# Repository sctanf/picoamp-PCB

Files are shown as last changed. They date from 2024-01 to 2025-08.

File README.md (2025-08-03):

# indexspeakerdacsmol

compact usb-i2s dac using rp2040 and max98360a for powering speakers, like index bmr drivers

* I forgot the silkscreen for usb pins, but they should be clear from below images.
* 0201 components suck to work with.
* intended to use with a usb-c cable, however the CC wire needs 5.1K pull-down to ground which I forgot about

firmware for the device is at https://github.com/sctanf/picoamp-2

pcb|3d|dev-pcb|dev-3d
--|--|--|--
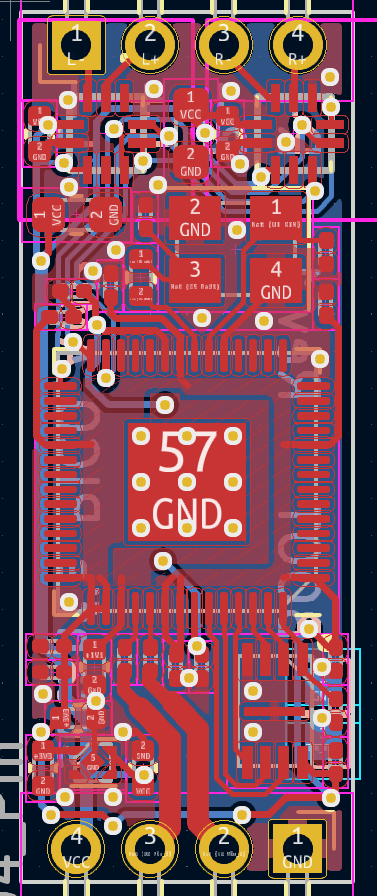
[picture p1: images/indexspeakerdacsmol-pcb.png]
pcb
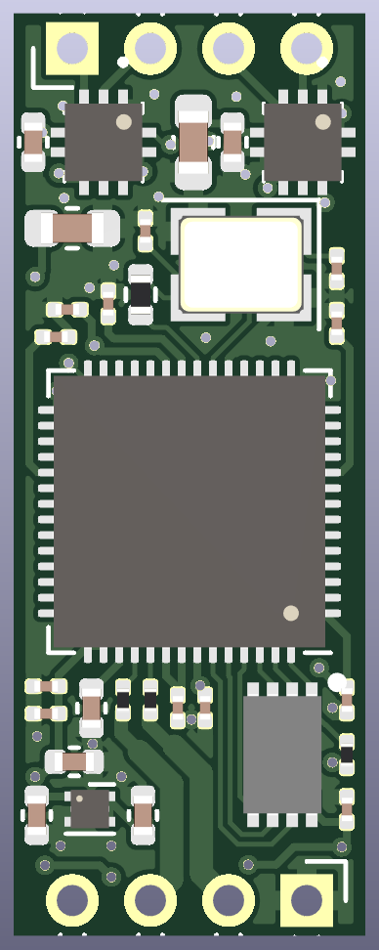
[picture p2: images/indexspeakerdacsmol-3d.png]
3d
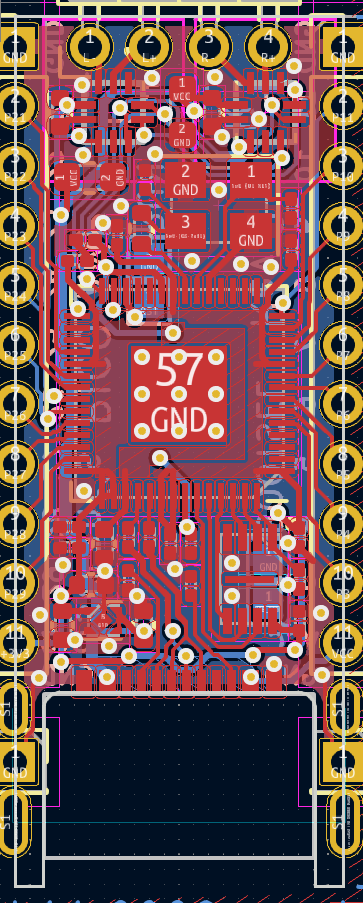
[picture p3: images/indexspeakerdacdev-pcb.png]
dev-pcb
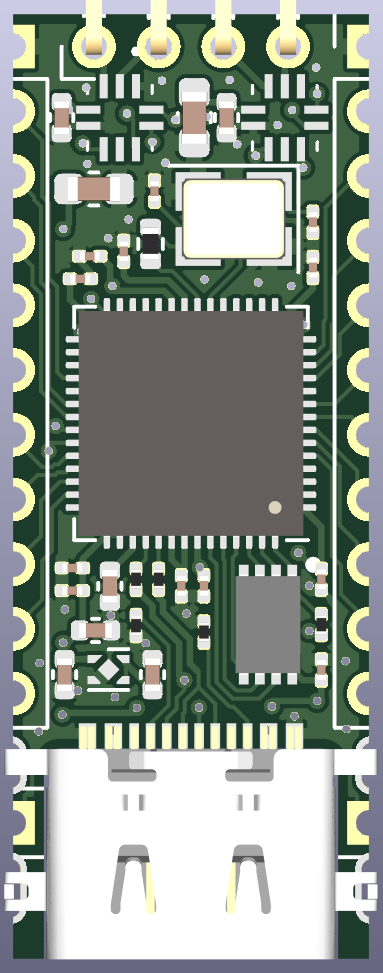
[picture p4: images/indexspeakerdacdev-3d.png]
dev-3d
|||

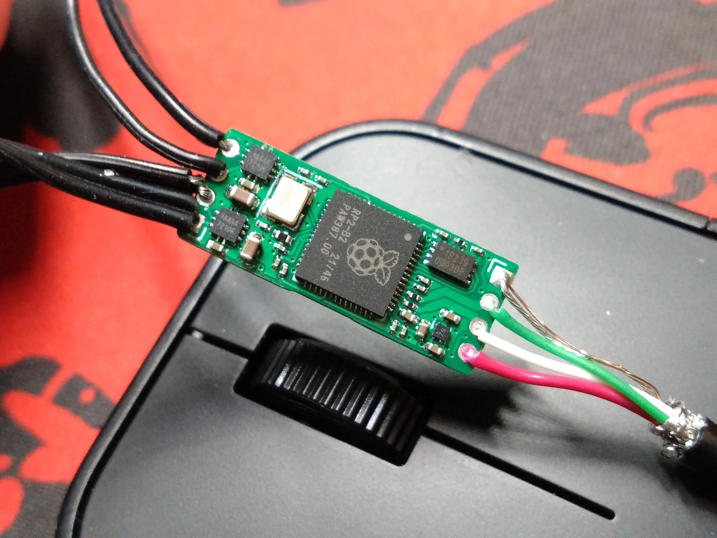
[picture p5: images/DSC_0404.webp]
finished board


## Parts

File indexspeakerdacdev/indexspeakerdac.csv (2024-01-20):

Reference | Value | Footprint | Datasheet | Manufacturer_Name | Manufacturer_Part_Number | Mouser Part Number | Qty
C1, C2 | 10uF | Capacitor_SMD:C_0603_1608Metric | ~ | Murata | GRM188C81A106MA73D | 81-GRM188C81A106MA3D | 2
C3, C4 | 0.1uF | Capacitor_SMD:C_0402_1005Metric | ~ | Murata | GRM155R61A104KA01J | 81-GRM15R61A104KA01J | 2
C5, C6 | 15pF | Capacitor_SMD:C_0201_0603Metric | ~ | Murata | GRM0335C1E150JA01D | 81-GRM0335C1E150JA1D | 2
C7, C8, C16, C18 | 1uF | Capacitor_SMD:C_0402_1005Metric | ~ | Murata | GRM155C81A105KA12J | 81-GRM155C81A105KA2J | 4
C12, C14, C15, C17, C19-C24 | 0.1uF | Capacitor_SMD:C_0201_0603Metric | ~ | Murata | GRM033C80J104KE15D | 81-GRM33C80J104KE15D | 10
IC1, IC2 | MAX98360AEFB+T | SamacSys_Parts:MAX98360AEFB | https://www.mouser.jp/datasheet/2/256/MAX98360A-MAX98360D-1839867.pdf | Analog Devices Inc. | MAX98360AEFB+T | 700-MAX98360AEFB+T | 2
IC3 | W25Q16JVUXIQ_TR | SamacSys_Parts:SON50P300X200X60-9N | https://componentsearchengine.com/Datasheets/1/W25Q16JVUXIQ TR.pdf | Winbond | W25Q16JVUXIQ TR | 454-W25Q16JVUXIQTR | 1
J1 | Conn_01x04_Pin | Connector_PinHeader_2.00mm:PinHeader_1x04_P2.00mm_Horizontal | ~ |  |  |  | 1
J2, J4 | Conn_01x11_Pin | Connector_PinHeader_2.00mm:PinHeader_1x11_P2.00mm_Vertical | ~ |  |  |  | 2
J3, J5 | Conn_01x01_Pin | Connector_PinHeader_2.00mm:PinHeader_1x01_P2.00mm_Vertical | ~ |  |  |  | 2
J6 | USB_C_Receptacle_USB2.0 |  | https://www.usb.org/sites/default/files/documents/usb_type-c.zip | Global Connector Technology (GCT) | USB4510-03-1-A | 640-USB4510031A | 1
R1 | 1k | Resistor_SMD:R_0402_1005Metric | ~ | Vishay | CRCW04021K00FKED | 71-CRCW0402-1.0K-E3 | 1
R2, R3 | 27R | Resistor_SMD:R_0201_0603Metric | ~ | YAGEO | RC0201FR-0727RL | 603-RC0201FR-0727RL | 2
R4 | 1k | Resistor_SMD:R_0201_0603Metric | ~ | Bourns | CR0201-FW-1001GLF | 652-CR0201FW-1001GLF | 1
R5, R6 | 5.1k | Resistor_SMD:R_0201_0603Metric | ~ | YAGEO | RC0201JR-075K1L | 603-RC0201JR-075K1L | 2
TP1-TP4 | TestPoint | TestPoint:TestPoint_Pad_1.0x1.0mm | ~ |  |  |  | 4
U1 | RP2040 | Package_DFN_QFN:QFN-56-1EP_7x7mm_P0.4mm_EP3.2x3.2mm | https://datasheets.raspberrypi.com/rp2040/rp2040-datasheet.pdf | Raspberry Pi | SC0914(7) | 358-SC09147 | 1
U2 | MIC5317-3.3xM5 | Package_DFN_QFN:UDFN-4-1EP_1x1mm_P0.65mm_EP0.48x0.48mm | https://ww1.microchip.com/downloads/aemDocuments/documents/OTH/ProductDocuments/DataSheets/MIC5317-High-Performance-Single-150mA-LDO-DS20006195B.pdf | Microchip | MIC5317-3.3YMT-TR | 494-MIC531733YMTTR | 1
Y1 | Crystal_GND24 | Crystal:Crystal_SMD_3225-4Pin_3.2x2.5mm | ~ | ECS | ECS-120-10-33-AGM-TR | 520-120-10-33-AGMT | 1

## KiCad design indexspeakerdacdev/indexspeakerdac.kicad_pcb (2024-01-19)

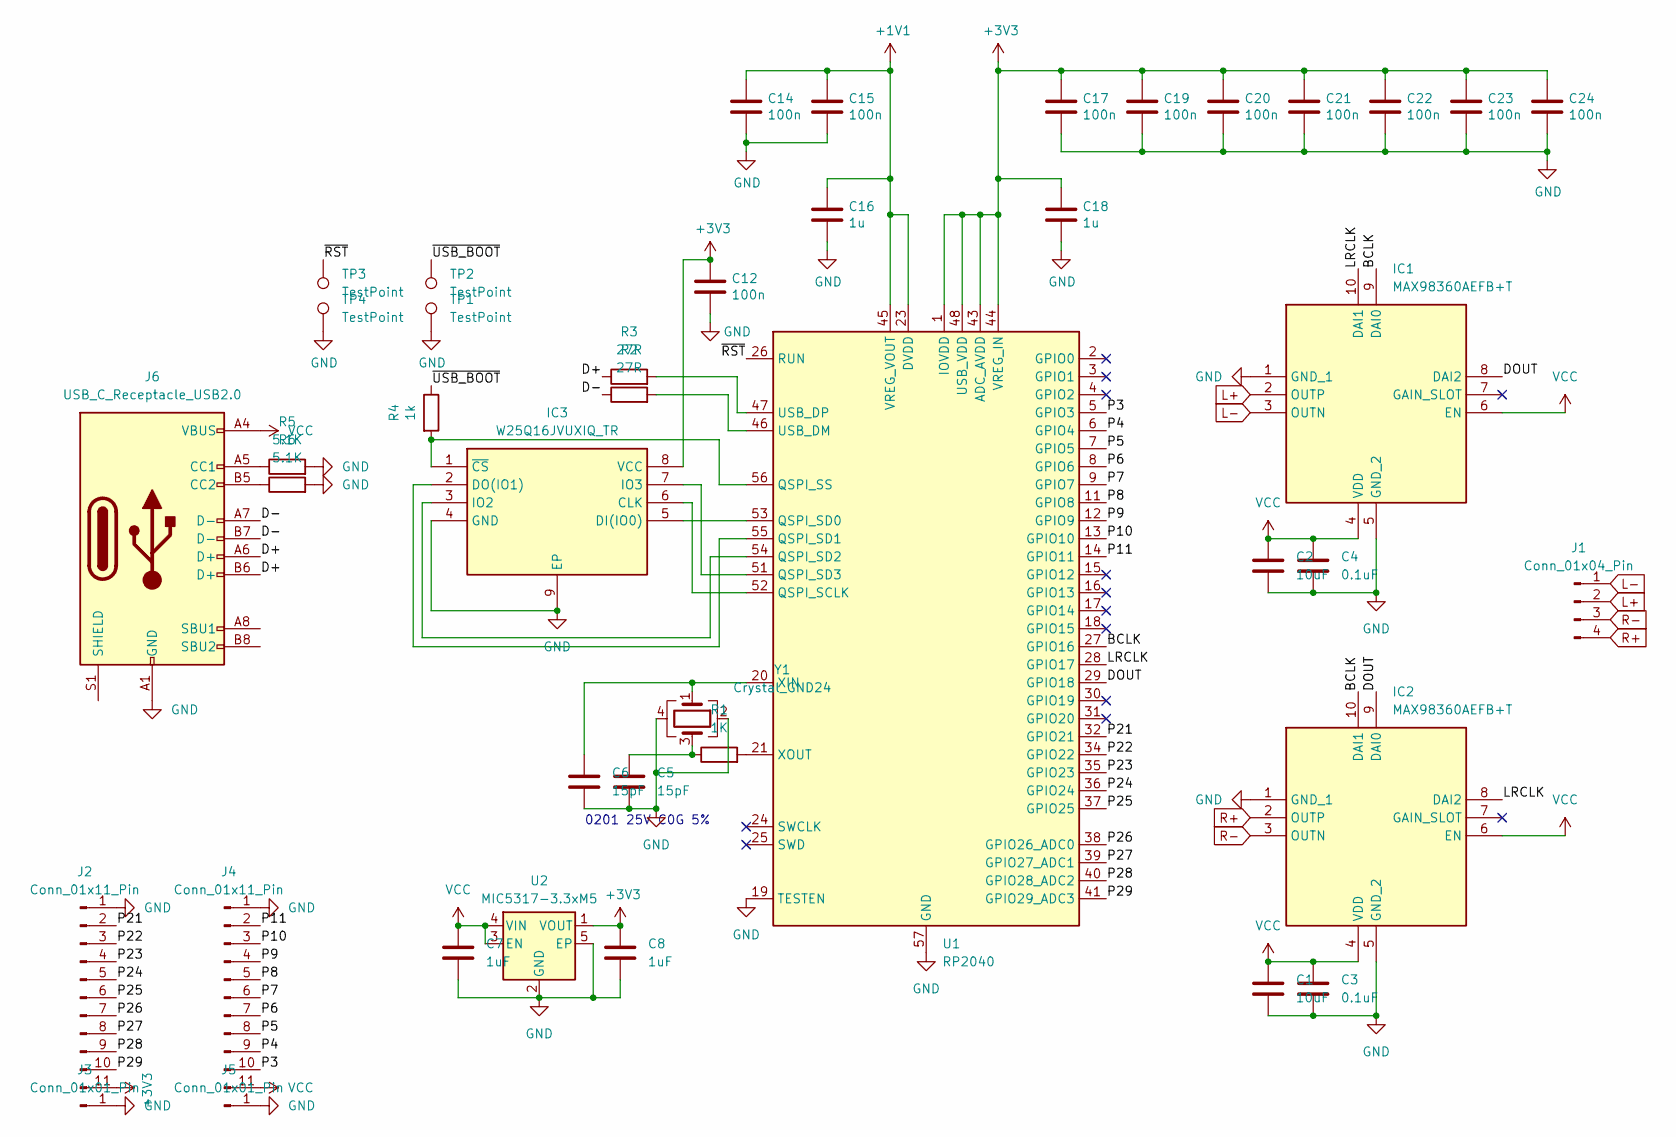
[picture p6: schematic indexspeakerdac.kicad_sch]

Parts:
C1, C2: 10uF; C_0603_1608Metric
C3, C4: 0.1uF; C_0402_1005Metric
C5, C6: 15pF; C_0201_0603Metric
C7, C8: 1uF; C_0402_1005Metric
C12, C14, C15, C17, C19, C20, C21, C22, C23, C24: 100n; C_0201_0603Metric
C16, C18: 1u; C_0402_1005Metric
IC1, IC2: MAX98360AEFB+T; MAX98360AEFB; Mouser Part Number 700-MAX98360AEFB+T
IC3: W25Q16JVUXIQ_TR; SON50P300X200X60-9N; Mouser Part Number 454-W25Q16JVUXIQTR
J1: Conn_01x04_Pin; PinHeader_1x04_P2.00mm_Horizontal
J2, J4: Conn_01x11_Pin; PinHeader_1x11_P2.00mm_Vertical
J3, J5: Conn_01x01_Pin; PinHeader_1x01_P2.00mm_Vertical
J6: USB_C_Receptacle_USB2.0
R1: 1K; R_0402_1005Metric
R2, R3: 27R; R_0201_0603Metric
R4: 1k; R_0201_0603Metric
R5, R6: 5.1K; R_0201_0603Metric
TP1, TP2, TP3, TP4: TestPoint; TestPoint_Pad_1.0x1.0mm
U1: RP2040; QFN-56-1EP_7x7mm_P0.4mm_EP3.2x3.2mm
U2: MIC5317-3.3xM5; UDFN-4-1EP_1x1mm_P0.65mm_EP0.48x0.48mm
Y1: Crystal_GND24; Crystal_SMD_3225-4Pin_3.2x2.5mm

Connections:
+1V1: C14.1, C15.1, C16.1, U1.23 (DVDD), U1.45 (VREG_VOUT), U1.50 (DVDD)
+3V3: C8.1, C12.1, C17.1, C18.1, C19.1, C20.1, C21.1, C22.1, C23.1, C24.1, IC3.8 (VCC), J2.11, U1.1 (IOVDD), U1.10 (IOVDD), U1.22 (IOVDD), U1.33 (IOVDD), U1.42 (IOVDD), U1.43 (ADC_AVDD), U1.44 (VREG_IN), U1.48 (USB_VDD), U1.49 (IOVDD), U2.1 (VOUT)
/BCLK: IC1.9 (DAI0), IC2.10 (DAI1), U1.27 (GPIO16)
/D+: J6.A6 (D+), J6.B6 (D+), R3.1
/D-: J6.A7 (D-), J6.B7 (D-), R2.1
/DOUT: IC1.8 (DAI2), IC2.9 (DAI0), U1.29 (GPIO18)
/LRCLK: IC1.10 (DAI1), IC2.8 (DAI2), U1.28 (GPIO17)
/P3: J4.10, U1.5 (GPIO3)
/P4: J4.9, U1.6 (GPIO4)
/P5: J4.8, U1.7 (GPIO5)
/P6: J4.7, U1.8 (GPIO6)
/P7: J4.6, U1.9 (GPIO7)
/P8: J4.5, U1.11 (GPIO8)
/P9: J4.4, U1.12 (GPIO9)
/P10: J4.3, U1.13 (GPIO10)
/P11: J4.2, U1.14 (GPIO11)
/P21: J2.2, U1.32 (GPIO21)
/P22: J2.3, U1.34 (GPIO22)
/P23: J2.4, U1.35 (GPIO23)
/P24: J2.5, U1.36 (GPIO24)
/P25: J2.6, U1.37 (GPIO25)
/P26: J2.7, U1.38 (GPIO26_ADC0)
/P27: J2.8, U1.39 (GPIO27_ADC1)
/P28: J2.9, U1.40 (GPIO28_ADC2)
/P29: J2.10, U1.41 (GPIO29_ADC3)
/~RST: TP3.1, U1.26 (RUN)
/~USB_BOOT: R4.1, TP2.1
GND: C1.2, C2.2, C3.2, C4.2, C5.2, C6.2, C7.2, C8.2, C12.2, C14.2, C15.2, C16.2, C17.2, C18.2, C19.2, C20.2, C21.2, C22.2, C23.2, C24.2, IC1.1 (GND_1), IC1.5 (GND_2), IC2.1 (GND_1), IC2.5 (GND_2), IC3.4 (GND), IC3.9 (EP), J2.1, J3.1, J4.1, J5.1, J6.A1 (GND), J6.A12 (GND), J6.B1 (GND), J6.B12 (GND), R5.2, R6.2, TP1.1, TP4.1, U1.19 (TESTEN), U1.57 (GND), U2.2 (GND), U2.5 (EP), Y1.2, Y1.4
L+: IC1.2 (OUTP), J1.2
L-: IC1.3 (OUTN), J1.1
unnamed: C5.1, R1.1, Y1.3
unnamed: IC3.6 (CLK), U1.52 (QSPI_SCLK)
unnamed: IC3.5 (DI(IO0)), U1.53 (QSPI_SD0)
unnamed: IC3.2 (DO(IO1)), U1.55 (QSPI_SD1)
unnamed: IC3.3 (IO2), U1.54 (QSPI_SD2)
unnamed: IC3.7 (IO3), U1.51 (QSPI_SD3)
unnamed: IC3.1 (~CS), R4.2, U1.56 (QSPI_SS)
unnamed: J6.A5 (CC1), R5.1
unnamed: J6.B5 (CC2), R6.1
unnamed: R2.2, U1.46 (USB_DM)
unnamed: R3.2, U1.47 (USB_DP)
unnamed: C6.1, U1.20 (XIN), Y1.1
unnamed: R1.2, U1.21 (XOUT)
R+: IC2.2 (OUTP), J1.4
R-: IC2.3 (OUTN), J1.3
VCC: C1.1, C2.1, C3.1, C4.1, C7.1, IC1.4 (VDD), IC1.6 (EN), IC2.4 (VDD), IC2.6 (EN), J4.11, J6.A4 (VBUS), J6.A9 (VBUS), J6.B4 (VBUS), J6.B9 (VBUS), U2.3 (EN), U2.4 (VIN)

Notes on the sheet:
0201 25V C0G 5%

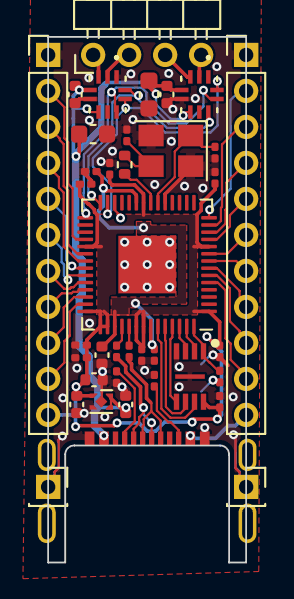
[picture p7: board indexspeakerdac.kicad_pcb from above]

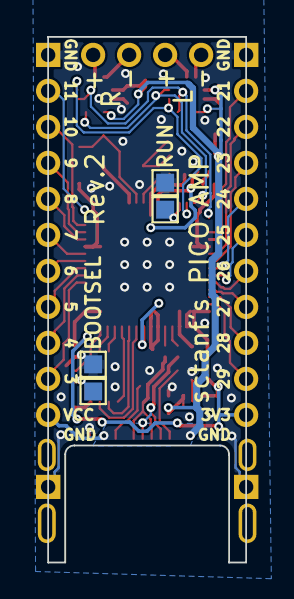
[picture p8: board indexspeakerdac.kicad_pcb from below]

Board: 2 copper layers, 11.0 x 29.2 mm, 42 parts (4 on the bottom side), 46 nets.

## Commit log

2024-01-16 add rev.2 board
    [indexspeakerdac.kicad_pcb, indexspeakerdac.kicad_sch]
2024-01-19 round connector cutout area
    [indexspeakerdac.kicad_pcb]
2024-01-20 add bom
    [indexspeakerdac.csv, indexspeakerdac.kicad_sch]
